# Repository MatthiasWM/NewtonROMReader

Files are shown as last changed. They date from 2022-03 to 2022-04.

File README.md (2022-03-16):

# NewtonROMReader

This archive contains the PCB layout and firmware source code for my Apple 
Newton MessagePad ROM board reader/programmer.

The Newton ROM Reader reads the contents of Apple MessagePad MP2x00 ROM
boards. Besides the well known US and German ROM, this programmer can read 
prototype ROM boards for further research.

Using the alternative Flash ROM Board, the ROM Reader can also program the
Flash chips and create new ROM Boards with patched or alternative 
operating systems. 

## CAUTION

 - Use an original Arduino Due. Do *NOT* use a Mega 2560!
 - Never insert or remove the ROM card while the programmer is powered!
 - All operations are final! There is no undo! There is no confirmation.

## Reader/Programmer

Assembling the Programmer requires some advanced soldering skills. The pin 
headers must be soldered around the outside of the board facing down. They 
must be flush with the PCB on the top, or the ROM board will not fit.

The SD Card connector is soldered to the underside of the board. The top
of the connector should be insulated using an ample amount of tape, avoiding
a short circuit with header pins on the Arduino. ALternatively, the colliding
pins on the Arduino board can be cut off.

The DIMM memory socket is more difficult to solder. The pin pitch is relatively
small. To make sure that the soldering is correct, the first tool to run
in the Programmer should be the short circuit test.

The last solder part is easy, but must not be forgotten. It's a jumper that 
sets the power to 3.2V. Connect the two eyes marked with an asterisk (*).

```
:
:   Lower left corner of the PCB
|
| ooo ooo
| ooo **o
|     ...... ........
+--------------------- - -
``` 

The Programmer board should be mounted on an Arduino Due. It *MUST NOT* be 
used with an Arduino Mega 1280/2560. The Mega runs at 5V and will likely
destroy any ROM, Flash, or SD card inserted into the Programmer. The Due runs
at the required 3.2V. If the large USB-A port of the Arduino blocks access to 
the SD Card slot, you have the wrong board!

The Programmer communicates with the user via USB connection to the Programming
port. No extra power connection is required. There is no extra software for
the Programmer. Users must use a serial terminal program to connect via the 
Programming USB port (57600 bps/baud 8N1).

## Firmware Source Code

The source code comes as an Arduino sketch `.ino` file and a number of 
additional source and header files. The "SdFat" library by Bill Greimann must be 
installed within the Arduino system `Tools > Manage Libraries...`.

Load the `.ino` file and set the board to `Arduino Due (Programming Port)`, 
then choose the right port from the `Tools > Port` menu.

Open the serial monitor `Tools > Serial Monitor` and press `Ctrl-U` to upload
the firmware to the Programmer.  

## PCB Layout

The Programmer PCB was designed with Eagle CAD 7.7.0 Stadard Edition. It's a
two layer board with no exeptional requirements.

The SO-DIMM 72 modules are not very common anymore and are somewhat hard to 
find. The SD Card socket is a standard SMD part. Pin headers should be 
square shaped to fit the Arduino receptacle well.

## Usage

The Programmer writes a 90's style menu over the USB serial port connection.
Functions can be selected by typing the command key and Return. 

 - `h`: Check all connectors on the board for short circuits. This tool helps
        verifying that there are no bridges in the SO DIMM connector soldering.
        *Never run this command with a ROM board or SD Card inserted!*
 - `0`: Select the ROM area from 0x00000000 to 0x00800000 which corresponds
        to the regular ROM and Apple system ROM extension (REx).
 - `1`: This page can be programmed with an extension block of up to 8MB.
 - `2`, `3`: Experimental blocks. These should be mapped to 0x10000000 and 
        can contain 8MB extensions each. This however is not yet verified.
 - `p`: Print the contents of the Flash as a hex dump with ASCII. Pressing 
        `return` will print the next block. Pressing any other key followed
        by `enter` will bring you back to the main menu. 
 - `c`: Check if the Flash memory is empty (all addresses return 0xFFFFFFFF).
 - `e`: Erase all sectors in the selected Flash area.
 - `w`: Write the content of a file on SD card or on an USB Drive to the 
        current Flash page. Filenames for pages 0 to 3 are set to "rom.bin",
        "rex1.bin", "rex2.bin", and "rex3.bin".
 - 'v': Verify the Flash content with the corresponding file on SD Card or 
        USB Drive.
  
## ToDo's

 - the SO DIMM footprint is really hard to solder, the pads are too big and 
   solder tends to short the pins
 - the LED can not be controlled because it is connected to a ROM Board output
 - address and data pins should be connected to 32 bit registers, making the 
   pin-by-pin addressing obsolete and the programmer much faster
 - the SPI port should be connected to a hardware SPI
 - there should be an option for a display and four buttons
 - the SD Card connecter must have pull-ups on most pins, and the Card 
   Detect and Write Protect pins should be connected to some pin

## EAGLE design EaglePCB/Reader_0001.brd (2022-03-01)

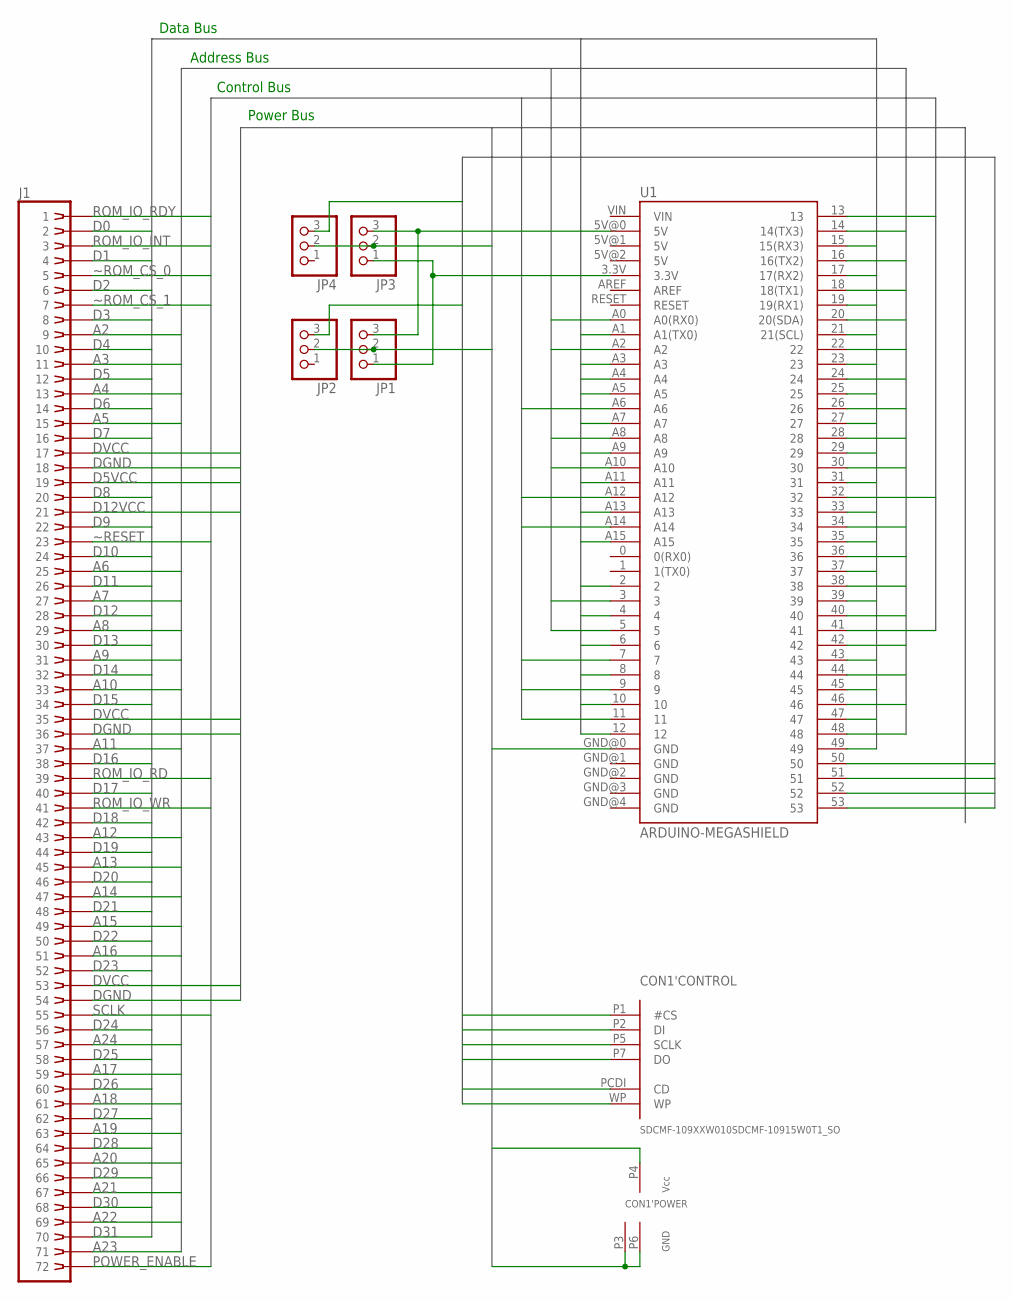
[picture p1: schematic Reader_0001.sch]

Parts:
CON1: SDCMF-109XXW010SDCMF-10915W0T1_SO; SDCMF-10915W0T1
J1: DIMM-M3; 177827-1
JP1, JP2, JP3, JP4: PINHD-1X3; 1X03
U1: ARDUINO-MEGASHIELD; ARDUINO_MEGA_SHIELD

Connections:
A2: J1.9, U1.5
A3: J1.11, U1.3
A4: J1.13, U1.A0 (A0(RX0))
A5: J1.15, U1.A2
A6: J1.25, U1.14 (14(TX3))
A7: J1.27, U1.16 (16(TX2))
A8: J1.29, U1.18 (18(TX1))
A9: J1.31, U1.20 (20(SDA))
A10: J1.33, U1.A8
A11: J1.37, U1.A10
A12: J1.43, U1.22
A13: J1.45, U1.24
A14: J1.47, U1.26
A15: J1.49, U1.28
A16: J1.51, U1.30
A17: J1.59, U1.36
A18: J1.61, U1.38
A19: J1.63, U1.40
A20: J1.65, U1.48
A21: J1.67, U1.46
A22: J1.69, U1.44
A23: J1.71, U1.42
A24: J1.57, U1.34
D0: J1.2, U1.12
D1: J1.4, U1.10
D2: J1.6, U1.8
D3: J1.8, U1.6
D4: J1.10, U1.4
D5: J1.12, U1.2
D5VCC: J1.19, JP1.2, JP2.2
D6: J1.14, U1.A1 (A1(TX0))
D7: J1.16, U1.A3
D8: J1.20, U1.A4
D9: J1.22, U1.A5
D10: J1.24, U1.A7
D11: J1.26, U1.15 (15(RX3))
D12: J1.28, U1.17 (17(RX2))
D12VCC: J1.21
D13: J1.30, U1.19 (19(RX1))
D14: J1.32, U1.21 (21(SCL))
D15: J1.34, U1.A9
D16: J1.38, U1.A11
D17: J1.40, U1.A13
D18: J1.42, U1.A15
D19: J1.44, U1.23
D20: J1.46, U1.25
D21: J1.48, U1.27
D22: J1.50, U1.29
D23: J1.52, U1.31
D24: J1.56, U1.33
D25: J1.58, U1.35
D26: J1.60, U1.37
D27: J1.62, U1.39
D28: J1.64, U1.49
D29: J1.66, U1.47
D30: J1.68, U1.45
D31: J1.70, U1.43
DGND: CON1.P3 (GND), CON1.P6 (GND), J1.18, J1.36, J1.54, U1.GND@0 (GND)
DVCC: CON1.P4 (VCC), J1.17, J1.35, J1.53, JP3.2, JP4.2
unnamed: JP1.3, JP3.3, U1.5V@0 (5V)
unnamed: JP1.1, JP3.1, U1.3.3V
POWER_ENABLE: J1.72, U1.41
ROM_IO_INT: J1.3, U1.11
ROM_IO_RD: J1.39, U1.A12
ROM_IO_RDY: J1.1, U1.13
ROM_IO_WR: J1.41, U1.A14
SCLK: J1.55, U1.32
SD_CD: CON1.PCDI (CD)
SD_CLCK: CON1.P5 (SCLK), U1.52
SD_CS: CON1.P1 (#CS), U1.53
SD_DI: CON1.P2 (DI), JP2.3, U1.51
SD_DO: CON1.P7 (DO), JP4.3, U1.50
SD_WP: CON1.WP
~RESET: J1.23, U1.A6
~ROM_CS_0: J1.5, U1.9
~ROM_CS_1: J1.7, U1.7

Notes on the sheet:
Data Bus
Address Bus
Control Bus
Power Bus

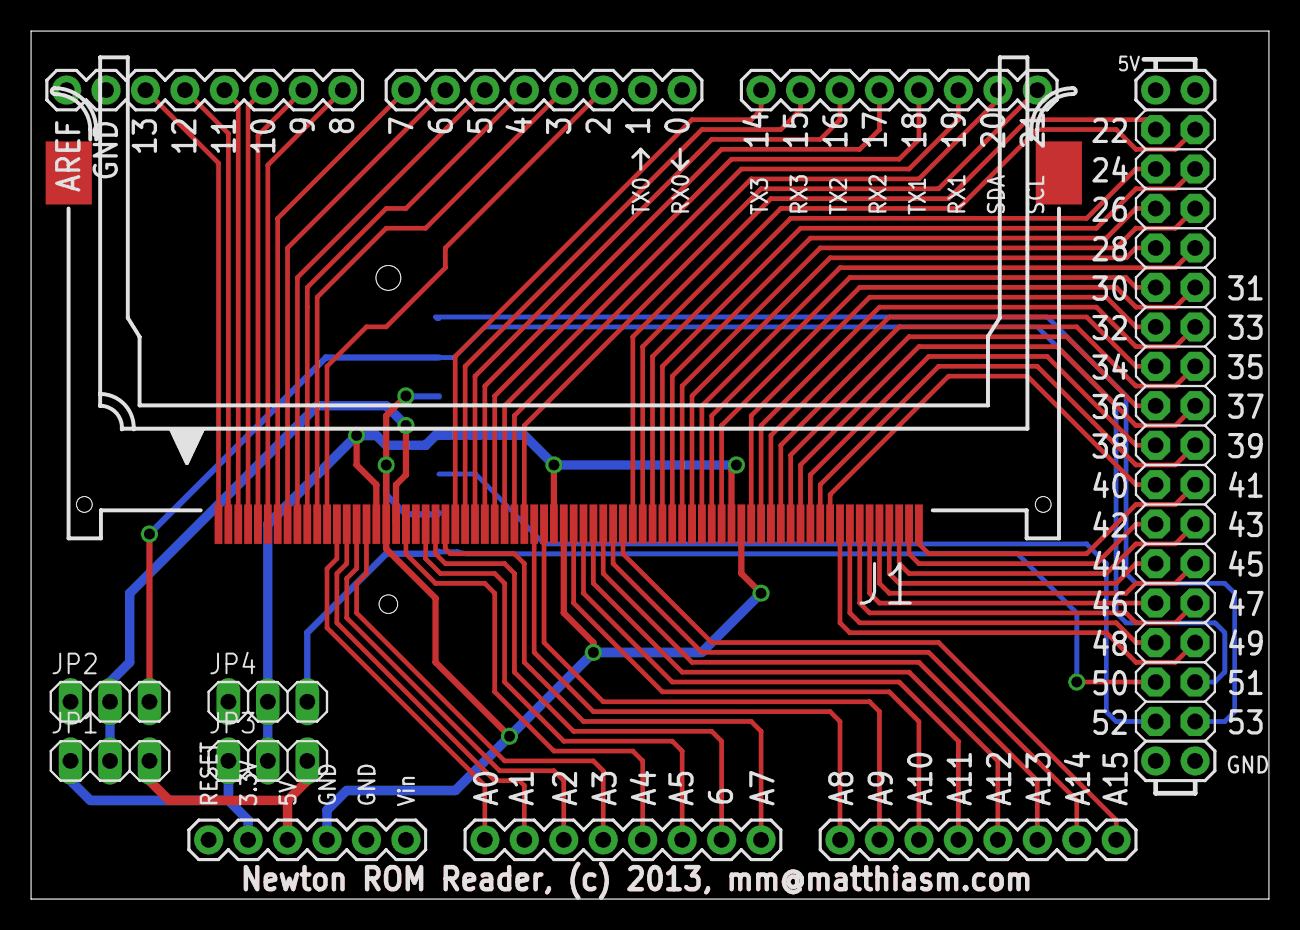
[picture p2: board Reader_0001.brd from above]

Board: 2 copper layers, 79.7 x 55.9 mm, 7 parts (1 on the bottom side), 73 nets.

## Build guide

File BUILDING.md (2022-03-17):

# Building the Hardware and Installing Software Components

 - Building the Newton ROM Reader PCB
 - Building the Newton ROM Reader firmware
 - Building the DCL Tools and Rex to generate ROM Extensions
 - (not yet) Installing the ARM Cross Assembler to Patch ROMs

## Building the Newton ROM Reader PCB

V1 of the ROM Reader PCB has a few issues, some of them are easy to fix, some are a bit more difficult.

Assembling the Programmer requires some advanced soldering skills. The pin 
headers must be soldered around the outside of the board facing down. They 
must be flush with the PCB on the top, or the ROM board will not fit.

The SD Card connector is soldered to the underside of the board. The top
of the connector should be insulated using an ample amount of tape, avoiding
a short circuit with header pins on the Arduino. Alternatively, the colliding
pins on the Arduino board can simply be cut off.

The DIMM memory socket is more difficult to solder. The pin pitch is relatively
small and the pads of the V1 board are too big. To make sure that the soldering 
is correct, the first tool to run in the Programmer should be the short circuit test.

There are three bridges that must be soldered. To amke sure that the board runs at
3.2V, a jumper that must be soldered, connecting the pins marked `1`. Two 10k 
resistors must be soldered, one connecting the pins marked `2`, and one connecting 
the pins marked `3`. Without resistors, the SD Card interface will not work
(Thanks to PCBman for finding this). 

The programmer will still recognize FAT32 fomatted USB Sticks, connect to the native
USB port via OTG cable.

```
:
:   Lower left corner of the PCB
|
| oo3 o22
| 3oo 11o
|     ...... ........
+--------------------- - -
``` 

The Programmer board should be mounted on an Arduino Due. It *MUST NOT* be 
used with an Arduino Mega 1280/2560. The Mega runs at 5V and will likely
destroy any ROM, Flash, or SD card inserted into the Programmer. The Due runs
at the required 3.2V. If the large USB-A port of the Arduino blocks access to 
the SD Card slot, you have the wrong board!

The Programmer communicates with the user via USB connection to the Programming
port. No extra power connection is required. There is no extra software for
the Programmer. Users must use a serial terminal program to connect via the 
Programming USB port (57600 bps/baud 8N1).

## Building the Newton ROM Reader firmware

To compile this firmware for the Newton ROM Programmer:

Downlaod and install the Arduino IDE (the developer environment) from [arduino.cc](https://www.arduino.cc/en/software).

Install the SdFat library by Bill Greiman, using the Arduino IDE menu `Tools > Manage Libraries...`.

Select the correct board via `Tools > Board > Arduino ARM 32 > Arduino Due (Programming Port)`. 
Connect to the Due `Programming Port` via USB and select the serial port `Tools > Port`.

Downlaod this project as a zip file or with `git clone`.
The archive *must* be located in a directory named `NewtonRomReader`. 
The Arduino IDE insists. Make sure you write `Rom`, not `ROM` in the filename
(Thanks to Pawel for finding this).

Open the `NewtonRomReader.ino` file in the Arduino developer environment.
It will open a single window with 12 or more  tabs for all the other source code files.

Press `Ctrl-R` (`Cmd-R` on Mac) and the program should compile (there may be warnings, but no errors).
Connect your Due and press `Ctrl-U` (`Cmd-U` on Mac) to upload your firmware into your Programmer.

Open the Serial Monitor that is part of the Arduino IDE (`Shift-Ctrl-M`, `Shift-Cmd-M`) and set the speed to 57600 baud.
You should see the ROM Programmer's menu on the serial port screen.

```
==============================
  Newton ROM Programmer V0.4
==============================

  h:  hardware test
  ...
```

Please run the hardware test before inserting any cards or testing anything else. If short circuits are found, brushing a dry 
toothbrush along the backside of the SO DIMM connector (the lengthy connector for the ROM Board) may fix the shorts.

## Building the DCL Tools and Rex to generate ROM Extensions

If you are planning to add Newton apps onto the ROM board, you need to get familiar with the _Rex_ tool. 
Rex is a command line tool that is part of the DCL toolbox. Compile and install Rex from the command line.

You will need to install [CMake](https://cmake.org/download/) and a C++ build environemnt (_Xcode_ on macOS, _VisualStudio_ on MSWindows,
_gcc_ on Linux).

```
# Download the source coee form GitHub:
git clone https://github.com/pguyot/DCL.git DCL.git
# Enter the source coee directory
cd DCL.git/
# Configure the build environment 
cmake -S . -B build -DCMAKE_BUILD_TYPE=Debug
# Build the library and the apps in DCL
cmake --build build/
# Installe Rex and other tools on your machine
cmake --install build/
```

Building a ROM Extension is explained [here](https://github.com/MatthiasWM/NewtonROMReader/wiki/Build-a-ROM-Extension).

## (todo) Installing the ARM Cross Assembler to Patch ROMs

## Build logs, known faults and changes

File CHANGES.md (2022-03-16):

## Versions

### Version 0.3 

Version 0.3 was mostly rewritten, adding support for USB Drives that can be 
connected to the native USB port via OTG cable. If no SD Card is found, we
check for a connected USB Drive. USB and SD drives can be hot swapped.

Menus were restructured, and menu commands were changed (sorry about that).
There is no longer a confirmation required for any operation, making it 
very easy to erase or overwrite a ROM with one keypress.

Pins are now set to inputs with a pullup after every operation, making an
accidental removal of a ROM card without powering down less harmful 
for the card.

### Version 0.2 

Version 0.2 is obsolete.

### Version 0.1 

The initial version is 0.1 which can erase, write, and verify the first ROM 
block and supports SD Cards.

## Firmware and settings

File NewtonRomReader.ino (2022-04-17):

// Please see BUILDING.md to build and install this file and other tools
//
// Written and tested for the Newton FLash ROM board with S29GL512 NOR Flash chips.
//

#include "NewtonRomReader.h"
#include "ROMCard.h"
#include "SDCard.h"
#include "menu.h"
#include "otg.h"

/**
 * Wait for a complete string, terminated by \n, while keeping the OTG system alive.
 * 
 * \return the string that was typed by the user, without the trailing \n.
 */
String serialReadString()
{
  String cmd;
//  int prevState = 0;
  for (;;) {
    if (uhgogo) {
      uhServer();
    }
//    if (uhstate.state!=prevState) {
//      printf("State changed from %d to %d\n", prevState, uhstate.state);
//      prevState = uhstate.state;
//    }
    if (Serial.available()>0) {
      char s = Serial.read();
      if (s=='\n')
        return cmd;
      if (s!='\r')
        cmd.concat(s);
    }
  }
}

/**
 * Print the name of a pin.
 * 
 * \param[in] i is *not* the pin number, but instead the position in the eggPin array.
 */
void printPin(int i)
{
  if (i > 44) {
    printf("A%d", i-43);
    return;
  }
  if (i > 12) {
    printf("D%d", i-13);
    return;
  }
  switch (i) {
    case 0: printf("SD_DO"); break;
    case 1: printf("SD_DI"); break;
    case 2: printf("SD_CLK"); break;
    case 3: printf("SD_CS"); break;
    case 4: printf("RESET"); break;
    case 5: printf("ROM_CS_0"); break;
    case 6: printf("ROM_CS_1"); break;
    case 7: printf("ROM_IO_RD"); break;
    case 8: printf("ROM_IO_WR"); break;
    case 9: printf("ROM_IO_INT"); break;
    case 10: printf("ROM_IO_RDY"); break;
    case 11: printf("POWER_ENABLE"); break;
    case 12: printf("SCLK"); break;
  }
}

// ---- CheckShortCicuits ------------------------------------

/**
 * Check if there are any short circuits between any of the
 * programmer pins and Vss.
 */
int testForShortCircuits()
{
  int nShorts = 0;
  
  printf("Check Programmer For Short Circuits...\n\n");
  
  // set all pins to input with pullup
  deactivateROMBus();
  deactivateSDBus();
  
  // check all pins for shortcuts agains ground
  printf("Testing for shorts to GND.\n");
  for (size_t i = 0; i < sizeof(eggPin); i++) {
    if (digitalRead(eggPin[i]) == 0) {
      printf("[ERROR] : Pin ");
      printPin(i);
      printf(" shorts with GND\n");
      nShorts++;
    }
  }
  
  // now check every pin against every other pin
  printf("Testing for shorts between pins.\n");
  for (size_t i = 0; i < sizeof(eggPin); i++) {
    digitalWrite(eggPin[i], 0);
    pinMode(eggPin[i], OUTPUT);
    for (size_t j = i + 1; j < sizeof(eggPin); j++) {
      if (digitalRead(eggPin[j]) == 0) {
        printf("[ERROR] : ");
        printPin(i);
        printf(" shorts with ");
        printPin(j);
        printf("\n");
        nShorts++;
      }
    }
    digitalWrite(eggPin[i], 1);
    pinMode(eggPin[i], INPUT_PULLUP);
  }

  // Give the user the result
  if (nShorts) {
    printf("\n[ERROR] : %d short circuits found.\n", nShorts);
    printf("[ERROR] : Please fix the board before using it.\n");
  } else {
    printf("\n[OK] : no short circuits found.\n");
  }

  return nShorts;
}

/**
 * User menu call to test board condition.
 */
void userCheckShortCicuits() {
  testForShortCircuits();
}

// ----------------------------------------------------------
// Verify the functions below.


// missing connection in Data lines: 00200000 => D21 = pin 48
// can't test all address lines without dumping the entire ROM

const  char *ascLut =
  "ABCDEFGHIJKLMNOP"
  "QRSTUVWXYZabcdef"
  "ghijklmnopqrstuv"
  "wxyz0123456789+/";


// 012345 670123 456701 234567 012345 67CCCC
void printEnc(unsigned long v)
{
  char d[7]; //, check = 0;
  d[0] = ascLut[v & 0x3f];
  v = v >> 6;
  d[1] = ascLut[v & 0x3f];
  v = v >> 6;
  d[2] = ascLut[v & 0x3f];
  v = v >> 6;
  d[3] = ascLut[v & 0x3f];
  v = v >> 6;
  d[4] = ascLut[v & 0x3f];
  v = v >> 6;
  d[5] = ascLut[v & 0x3f];
  d[6] = 0;
  printf("%s", d);
}

void writeFlash(uint32_t addr, uint32_t data)
{
  if (addr & 0x00000003) {
    printf("[INTERNAL_ERROR] : writeFlash: address must be word aligned: 0x%08lx\n", addr);
    return;
  }
  writeWord(0x0555 << 2, 0x00AA00AA);
  writeWord(0x02AA << 2, 0x00550055);
  writeWord(0x0555 << 2, 0x00A000A0);
  writeWord(addr, data);
  // FIXME: read status register
  delay(10);
  uint32_t w = readWord(addr);
  if (w != data) {
    printf("[ERROR] : readback failed at 0x%08lx: 0x%08lx!=0x%08lx\n",
           addr, data, w);
  }
}

// ---- Print Memory -----------------------------------------

/**
 * Read 512 bytes from memory and print a hex dump.
 * 
 * \param[in] addr start printing from this address
 * \return true
 */
bool printMemoryBlock(uint32_t addr) 
{
  activateControlBus();
  activateAddressBus();
  activateDataBusRead();

  for (uint32_t i=0; i<512; i+=16) {
    printf("%08lx: ", addr+i);
    uint32_t data[4];
    for (uint32_t j=0; j<4; j++) {
      data[j] = readWord(addr + i + j*4);
    }
    for (uint32_t j=0; j<4; j++) {
      printf("%08lx", data[j]);
    }
    printf(" |");
    for (uint32_t j=0; j<4; j++) {
      uint8_t c = data[j]>>24;
      printf("%c", (c<32||c>126) ? '.' : c);
      c = data[j]>>16;
      printf("%c", (c<32||c>126) ? '.' : c);
      c = data[j]>>8;
      printf("%c", (c<32||c>126) ? '.' : c);
      c = data[j];
      printf("%c", (c<32||c>126) ? '.' : c);
    }
    printf("|\n");
  }

  deactivateDataBus();
  deactivateAddressBus();
  deactivateControlBus();

  return true;
}

/**
 * Interactively print memeory blocks for current page.
 */
void userPrintMemory()
{
  uint32_t addr = gPageList[gCurrentPage].pStart;
  for (;;) {
    printMemoryBlock(addr);
    printf("Press [return] to continue, 'a'+[return] to abort.\n");
    String s = serialReadString();
    if (s.length()!=0) return;
    addr += 512;
  }
}

// ---- Test Empty -------------------------------------------

/**
 * Check if a block of memory is empty, i.e. all 0xffffffff.
 * 
 * \param[in] inStart check starting at this address
 * \param[in] inEnd check up to this address
 * 
 * \return true if the block is empty
 */
bool checkEmpty(uint32_t inStart, uint32_t inEnd)
{
  bool aborted = false;
  bool empty = true;
  printf("Press Return to abort:\n");
  printf(".___.___.___.___.___.___.___.___.\n|");
  fflush(stdout);
  
  activateControlBus();
  activateAddressBus();
  activateDataBusRead();
  
  for (uint32_t addr = inStart; addr < inEnd; addr += 4) {
    uint32_t v = readWord(addr);
    if (v != 0xFFFFFFFF) {
      printf("\nValue mismatch at address 0x%08lx: 0x%08lx\n", addr, v);
      empty = false;
      break;
    }
    if (Serial.read() == '\n') {
      aborted = true;
      break;
    }
    if ((addr & 0x0003ffff) == 0) {
      printf(":"); 
      fflush(stdout);
    }
  }
  
  deactivateDataBus();
  deactivateAddressBus();
  deactivateControlBus();

  printf("\n");
  if (aborted)
    printf("[Aborted] : Test aborted by user.\n");
  else if (empty)
    printf("[OK] : Flash memory is empty and ready to be programmed.\n");
  else
    printf("[Warning] : Flash memory is not empty.\n");
    
  return empty;
}

// ---- Erase Flash Memory -----------------------------------

/**
 * Erase a block of memory (set it to all 0xffffffff).
 * 
 * \param[in] inStart erase process starting at this address
 * \param[in] inEnd erase up to this address
 * 
 * \return true if the erase op did not trigger an error
 */
bool eraseFlash(uint32_t inStart, uint32_t inEnd)
{
  // Status:     bit7==0 if busy
  // if bit7==1: bit5==0 if erase successful
  //             bit4==0 if programming was successful

  const int kEraseTimeout = 200;
  int err = 0;
  printf("Press Return to abort:\n");
  printf(".___.___.___.___.___.___.___.___.\n|");
  fflush(stdout);

  activateControlBus();
  activateAddressBus();
  activateDataBusRead();

  uint32_t addr;
  for (addr = inStart; addr < inEnd; addr += 0x00040000) {
    uint32_t w;
    // clear status register
    writeWord(0x0555 << 2, 0x00710071);
    // Erase a sector (sector size id 0x00040000):
    writeWord(0x0555 << 2, 0x00AA00AA);
    writeWord(0x02AA << 2, 0x00550055);
    writeWord(0x0555 << 2, 0x00800080);
    writeWord(0x0555 << 2, 0x00AA00AA);
    writeWord(0x02AA << 2, 0x00550055);
    writeWord(addr, 0x00300030);
    int i;
    for (i = 0; i < kEraseTimeout; i++) {
      // read status register
      writeWord(0x0555 << 2, 0x00700070);
      w = readWord(0);
      if ((w & 0x00800080) == 0x00800080)
        break;
      delay(10); // Typical erase time: 62 * 10us = .6 seconds
    }
    if (i == kEraseTimeout) { // operation timed out
      err = 1; // timeout
      break;
    }
    if ((w & 0x00200020) != 0x00000000) {
      err = 3; // erase operation failed
      break;
    }
    if (Serial.read() == '\n') {
      err = 2; // aborted
      break;
    }
    printf(":");
    fflush(stdout);
  }

  deactivateDataBus();
  deactivateAddressBus();
  deactivateControlBus();

  printf("\n");
  if (err==0) 
    printf("[OK] : Flash memory is erased and ready to be programmed.\n");
  else if (err==1)
    printf("[ERROR] : Timeout error at address 0x%08lx.\n", addr);
  else if (err==2)
    printf("[Aborted] : Operation aborted by user.\n");
  else if (err==3)
    printf("[ERROR] : Erase operation failed at address 0x%08lx.\n", addr);
    
  return (err==0);
}

// ---- Program ROM File -------------------------------------

/**
 * Program the contents of a file on SD Card or an OTG Drive to a block of Flash memory .
 * 
 * \param[in] inStart programming process starting at this address
 * \param[in] inEnd program up to this address or until the end of file
 * \param[in] inFilename write contents to this file
 * 
 * \return true if the write op did not trigger an error or warning
 */
bool programFlash(uint32_t inStart, uint32_t inEnd, String inFilename)
{
  const int kWriteTimeout = 100;
  int err = 0;
  bool useSD = true;
  FIL fd;

  if (initSDCard()==false) {
    if (uhstate.state!=UHSTAT_READY) {
      printf("[ERROR] : No SD card found, no USB drive found.\n");
      return false;
    }
    useSD = false;
  }

  if (useSD) {
    if (!file.open(inFilename.c_str(), O_RDONLY)) {
      printf("[ERROR] : Can't open file \"%s\" on SD card.\n", inFilename.c_str());
      return false;
    }
  } else {
    if (f_open(&fd, inFilename.c_str(), FA_READ) != 0) {
      printf("[ERROR] : Can't open file \"%s\" on USB drive.\n", inFilename.c_str());
      return false;
    }
  }
  
  printf("Press Return to abort:\n");
  printf(".___.___.___.___.___.___.___.___.\n|");
  fflush(stdout);
  
  activateControlBus();
  activateAddressBus();
  activateDataBusRead();

  const uint32_t nWords = 256;
  uint32_t addr;
  for (addr = inStart; addr < inEnd; addr += (4*nWords)) {
    // write sequence to prepare Flash for programming
    writeWord(0x0555 << 2, 0x00AA00AA);
    writeWord(0x02AA << 2, 0x00550055);
    writeWord(addr, 0x00250025); // addr should be SA
    writeWord(addr, ((nWords-1)<<16)|(nWords-1)); // addr should be SA, arg is number of words to write minus one
    // write buffer
    for (uint32_t j=0; j<nWords; j++) {
      uint32_t vFile = 0xffffffff;
      if (useSD) {
        int n = file.read(&vFile, 4);
        vFile = htonl(vFile);
        if (n==0) err = 4;
      } else {
        UINT n = 0;
        f_read (&fd, &vFile, 4, &n);
        vFile = htonl(vFile);
        if (n==0) err = 4;
      }
      writeWord(addr+(j<<2), vFile);
    }
    // confirm write
    writeWord(addr, 0x00290029); // addr should be SA
    // wait for operation to complete
    int t;
    uint32_t w;
    for (t = 0; t < kWriteTimeout; t++) {
      // read status register
      writeWord(0x0555 << 2, 0x00700070);
      w = readWord(0);
      if ((w & 0x00800080) == 0x00800080)
        break;
      delay(1); // There should be little to no delay needed.
    }
    if (t == kWriteTimeout) {
      err = 2; // timeout
      break;
    }
    if ((w & 0x00100010) != 0x00000000) {
      err = 3; // write operation failed
      break;
    }
    if (Serial.read() == '\n') {
      err = 1; // aborted
      break;
    }
    if (err==4)
      break;
    if ((addr & 0x0003ffff) == 0) {
      printf(":");
      fflush(stdout);
    }
  }

  deactivateDataBus();
  deactivateAddressBus();
  deactivateControlBus();

  if (useSD) {
    file.close();
    sd.end();
  } else {
    f_close(&fd);
  }

  printf("\n");
  if (err==0)
    printf("[OK] : Successfully programmed Flash memory with file contents.\n");
  else if (err==1)
    printf("[Aborted] : Operation aborted by user. Flash memory partially written.\n");
  else if (err==2)
    printf("[ERROR] : Write operation timed out at address 0x%08lx.\n", addr);
  else if (err==3)
    printf("[ERROR] : Write operation failed at address 0x%08lx.\n", addr);
  else if (err==4)
    printf("[Warning] : Successfully programmed Flash to end of file at address 0x%08lx.\n"
           "            Remaining memory unchanged.\n", addr);
    
  return (err==0);
}

// ---- Verify Flash Memory Block -------------------------------------

/**
 * Verify a block of Flash memeory to a file on SD Card or an OTG Drive.
 * 
 * \param[in] inStart verification process starting at this address
 * \param[in] inEnd verify up to this address or until the end of file
 * \param[in] inFilename compare to this file
 * 
 * \return true if the verify op did not trigger an error
 */
bool verifyFlash(uint32_t inStart, uint32_t inEnd, String inFilename)
{
  int err = 0;
  bool useSD = true;
  FIL fd;

  if (initSDCard()==false) {
    if (uhstate.state!=UHSTAT_READY) {
      printf("[ERROR] : No SD card found, no USB drive found.\n");
      return false;
    }
    useSD = false;
  }

  if (useSD) {
    if (!file.open(inFilename.c_str(), O_RDONLY)) {
      printf("[ERROR] : Can't open file \"%s\" on SD card.\n", inFilename.c_str());
      return false;
    }
  } else {
    if (f_open(&fd, inFilename.c_str(), FA_READ) != 0) {
      printf("[ERROR] : Can't open file \"%s\" on USB drive.\n", inFilename.c_str());
      return false;
    }
  }
  
  printf("Press Return to abort:\n");
  printf(".___.___.___.___.___.___.___.___.\n|");
  fflush(stdout);
  
  activateControlBus();
  activateAddressBus();
  activateDataBusRead();
  
  uint32_t addr, vFile, vFlash;
  for (addr = inStart; addr < inEnd; addr += 4) {
    vFile = vFlash = 0xffffffff;
    if (useSD) {
      int n = file.read(&vFile, 4);
      vFile = htonl(vFile);
      if (n<=0) {
        err = 3;
        break;
      }
    } else {
      UINT n = 0;
      f_read (&fd, &vFile, 4, &n);
      vFile = htonl(vFile);
      if (n<=0) {
        err = 3;
        break;
      }
    }
    vFlash = readWord(addr);
    if (vFlash != vFile) {
      err = 2;
      break;
    }
    if (Serial.read() == '\n') {
      err = 1;
      break;
    }
    if ((addr & 0x0003ffff) == 0) {
      printf(":");
      fflush(stdout);
    }
  }
  
  deactivateDataBus();
  deactivateAddressBus();
  deactivateControlBus();

  if (useSD) {
    file.close();
    sd.end();
  } else {
    f_close(&fd);
  }

  printf("\n");
  if (err==0)
    printf("[OK] : Flash memory and file contents are the same.\n");
  else if (err==1)
    printf("[Aborted] : Operation aborted by user.\n");
  else if (err==2)
    printf("[ERROR] : Contents differs at address 0x%08lx (0x%08lx!=0x%08lx).\n", addr, vFlash, vFile);
  else if (err==3)
    printf("[Warning] : Contents is the same up to end of file at address 0x%08lx.\n"
           "            Remaining memory unchecked.\n", addr);
    
  return (err==0);
}

void verifyFlash(Page &inPage)
{
  verifyFlash(inPage.pStart, inPage.pEnd, inPage.pFilename);
}

// ---- Read Flash Memory Block and write it to Mass Storage -------------------------------------

/**
 * Read a block of Flash memeory and write it to a file on SD Card or an OTG Drive.
 * 
 * \param[in] inStart copying process starting at this address
 * \param[in] inEnd copy up to this address
 * \param[in] inFilename overwrite this file
 * 
 * \return true if the copy op did not trigger an error
 */
bool readFlash(uint32_t inStart, uint32_t inEnd, String inFilename)
{
  int err = 0;
  bool useSD = true;
  FIL fd;

  if (initSDCard()==false) {
    if (uhstate.state!=UHSTAT_READY) {
      printf("[ERROR] : No SD card found, no USB drive found.\n");
      return false;
    }
    useSD = false;
  }

  if (useSD) {
    if (!file.open(inFilename.c_str(), O_WRONLY)) {
      printf("[ERROR] : Can't open file \"%s\" on SD card.\n", inFilename.c_str());
      return false;
    }
  } else {
    // http://mercury.pr.erau.edu/~siewerts/cec450/code/FreeRTOSExampleCode/Demo/Common/FileSystem/FatFs-0.7e/doc/en/open.html
    if (f_open(&fd, inFilename.c_str(), FA_WRITE|FA_CREATE_ALWAYS) != 0) {
      printf("[ERROR] : Can't open file \"%s\" on USB drive.\n", inFilename.c_str());
      return false;
    }
  }
  
  printf("Press Return to abort:\n");
  printf(".___.___.___.___.___.___.___.___.\n|");
  fflush(stdout);
  
  activateControlBus();
  activateAddressBus();
  activateDataBusRead();
  
  uint32_t addr, vFlash;
  for (addr = inStart; addr < inEnd; addr += 4) {
    vFlash = readWord(addr);
    vFlash = htonl(vFlash);
    if (useSD) {
      int n = file.write(&vFlash, 4);
      if (n<=0) {
        err = 3;
        break;
      }
    } else {
      UINT n = 0;
      f_write(&fd, &vFlash, 4, &n);
      if (n<=0) {
        err = 3;
        break;
      }
    }
    if (Serial.read() == '\n') {
      err = 1;
      break;
    }
    if ((addr & 0x0003ffff) == 0) {
      printf(":");
      fflush(stdout);
    }
  }
  
  deactivateDataBus();
  deactivateAddressBus();
  deactivateControlBus();

  if (useSD) {
    file.close();
    sd.end();
  } else {
    f_close(&fd);
  }

  printf("\n");
  if (err==0)
    printf("[OK] : Flash memory copied to file.\n");
  else if (err==1)
    printf("[Aborted] : Operation aborted by user.\n");
  else if (err==3)
    printf("[Warning] : Copying Flash memory to file failed at address 0x%08lx.\n", addr);
    
  return (err==0);
}

void readFlash(Page &inPage)
{
  readFlash(inPage.pStart, inPage.pEnd, inPage.pFilename);
}

// ---- Test 1 -----------------------------------------------

// ROM Board connectors:
//        X[------ address bus --------]
// 3322.2222:2222.1111:1111.11
// 1098.7654:3210.9876:5432.1098:7654.3210
// CS0 --> A25
// CS0 & CS1 --> CE
//
//  CS0 CS1 | A25 CE
// ---------+--------
//   0   0  |  0   0  - not allowed
//   0   1  |  0   0  - access 0x0000.0000 to 0x01ff.ffff (32MB)
//   1   0  |  1   0  - access 0x0200.0000 to 0x03ff.ffff (32MB)
//   1   1  |  1   1  - ROM disabled
//
//  Programmer   MessagePad
//   Address      Address     ID    page #, filename
// ----------------------------------------------------------
// 0x0000.0000: 0x0000.0000: ROM   (page 0, rom.bin)
// 0x0080.0000: 0x0080.0000: REx1  (page 1, rex1.bin)
// 0x0100.0000: 0x0100.0000: fault, but could probably be mapped to REx2
// 0x0180.0000: 0x0180.0000: fault, but could probably be mapped to REx3
// 0x0200.0000: 0x1000.0000: REx4  (page 2, rex2.bin)
// 0x0280.0000: 0x1080.0000: REx5  (page 3, rex3.bin)
// 0x0300.0000: 0x1100.0000: REx6
// 0x0380.0000: 0x1180.0000: REx7
//              0x1200.0000: REx4 mirror prev ROMs up to 0x2000.0000

/**
 * This writes a unique value at every 8MB block. 
 * 
 * I used Hammer to find these blocks again on the MessagePad. Turns 
 * out that the first 16MB of ROM are mapped to address 0. The second 
 * 16MB block is not mapped, but I have a feeling that modifying the 
 * MMU LUT could map this block into the second 16MB of the system. 
 * They would not be discovered by the NewtonOS though.
 * 
 * The upper 32MB of our board are mapped to 0x1000.0000. The first 
 * 16MB can contain more ROM Extensions. I don't know if the remain 
 * 16MB can be used by the OS.
 */
void userTest1()
{
//eraseFlash(0x00000000, 0x00000000); // ROM + Apple REX 0
//eraseFlash(0x00800000, 0x00800000); // REX 1
  eraseFlash(0x01000000, 0x01000000); // REX 2
  eraseFlash(0x01800000, 0x01800000); // REX 3
  eraseFlash(0x02000000, 0x02000000); // ??
  eraseFlash(0x02800000, 0x02800000); // ??
  eraseFlash(0x03000000, 0x03000000); // ??
  eraseFlash(0x03800000, 0x03800000); // ??

  activateControlBus();
  activateAddressBus();
  activateDataBusRead();
  
  writeFlash(0x01000000, 0x52457832); // "REx2"
  writeFlash(0x01800000, 0x52457833);
  writeFlash(0x02000000, 0x52457834);
  writeFlash(0x02800000, 0x52457835);
  writeFlash(0x03000000, 0x52457836);
  writeFlash(0x03800000, 0x52457837);
  
  deactivateDataBus();
  deactivateAddressBus();
  deactivateControlBus();
}

// -----------------------------------------------------------

void userCheckEmpty(int inPage)
{
  if (inPage==-1) 
  inPage = gCurrentPage;
  Page &pg = gPageList[inPage];
  printf("Checking if \"%s\" is empty...\n", gPageList[gCurrentPage].pName);
  checkEmpty(pg.pStart, pg.pEnd);
}

void userErasePage(int inPage)
{
  if (inPage==-1) 
  inPage = gCurrentPage;
  Page &pg = gPageList[inPage];

  printf("Erasing \"%s\"...\n", gPageList[gCurrentPage].pName);
  eraseFlash(pg.pStart, pg.pEnd);
}
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
void loop()
{
  printf("\n\n");
  printf("==============================\n");
  printf("  Newton ROM Programmer V0.4\n");
  printf("==============================\n\n");
  
  for (auto &menuitem : gMenuItemList) {
    menuitem->print();
  }
  
  printf("Current page is \"%s\" (\"%s\").\n",
         gPageList[gCurrentPage].pName,
         gPageList[gCurrentPage].pFilename);
  
  printf("\n> ");
  fflush(stdout);
  String s = serialReadString();
  printf("%s\n\n", s.c_str());
  
  for (auto &menuitem : gMenuItemList) {
    if (s.equals(menuitem->cmd())) {
      menuitem->run();
      break;
    }
  }
}

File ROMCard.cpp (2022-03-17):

#include "ROMCard.h"

int gCurrentPage = 0;
uint32_t gCurrentAddress = 0;

static bool sAddressPinsUndefined = true;

std::vector <Page> gPageList = {
  { 0x00000000, 0x00800000, "ROM page", "rom.bin" },
  { 0x00800000, 0x01000000, "ROM Extension 1", "rex1.bin" },
  { 0x02000000, 0x02800000, "ROM Extension 2", "rex2.bin" },
  { 0x02800000, 0x03000000, "ROM Extension 3", "rex3.bin" },
  { 0x00000000, 0x01000000, "ROM & ext1", "romrex1.bin" },
  { 0x02000000, 0x03000000, "ext2 & ext3", "rex23.bin" },
//{ 0x00000000, 0x02000000, "full card", "card.bin" },
};


void dataBus(bool active)
{
  int mode = active ? OUTPUT : INPUT_PULLUP;
//  int mode = active ? OUTPUT : INPUT;
  pinMode(eggD0, mode);
  pinMode(eggD1, mode);
  pinMode(eggD2, mode);
  pinMode(eggD3, mode);
  pinMode(eggD4, mode);
  pinMode(eggD5, mode);
  pinMode(eggD6, mode);
  pinMode(eggD7, mode);
  pinMode(eggD8, mode);
  pinMode(eggD9, mode);
  pinMode(eggD10, mode);
  pinMode(eggD11, mode);
  pinMode(eggD12, mode);
  pinMode(eggD13, mode);
  pinMode(eggD14, mode);
  pinMode(eggD15, mode);
  pinMode(eggD16, mode);
  pinMode(eggD17, mode);
  pinMode(eggD18, mode);
  pinMode(eggD19, mode);
  pinMode(eggD20, mode);
  pinMode(eggD21, mode);
  pinMode(eggD22, mode);
  pinMode(eggD23, mode);
  pinMode(eggD24, mode);
  pinMode(eggD25, mode);
  pinMode(eggD26, mode);
  pinMode(eggD27, mode);
  pinMode(eggD28, mode);
  pinMode(eggD29, mode);
  pinMode(eggD30, mode);
  pinMode(eggD31, mode);
}

void activateDataBusWrite() { dataBus(true); }
void activateDataBusRead() { dataBus(false); }
void deactivateDataBus() { dataBus(false); }

void addressBus(bool active)
{
  int mode = active ? OUTPUT : INPUT_PULLUP;
  pinMode(eggA2, mode);    // 0x00000004
  pinMode(eggA3, mode);    // 0x00000008
  pinMode(eggA4, mode);    // 0x00000010
  pinMode(eggA5, mode);    // 0x00000020
  pinMode(eggA6, mode);    // 0x00000040
  pinMode(eggA7, mode);    // 0x00000080
  pinMode(eggA8, mode);    // 0x00000100
  pinMode(eggA9, mode);    // 0x00000200
  pinMode(eggA10, mode);   // 0x00000400
  pinMode(eggA11, mode);   // 0x00000800
  pinMode(eggA12, mode);   // 0x00001000
  pinMode(eggA13, mode);   // 0x00002000
  pinMode(eggA14, mode);   // 0x00004000
  pinMode(eggA15, mode);   // 0x00008000
  pinMode(eggA16, mode);   // 0x00010000
  pinMode(eggA17, mode);   // 0x00020000
  pinMode(eggA18, mode);   // 0x00040000
  pinMode(eggA19, mode);   // 0x00080000
  pinMode(eggA20, mode);   // 0x00100000
  pinMode(eggA21, mode);   // 0x00200000
  pinMode(eggA22, mode);   // 0x00400000
  pinMode(eggA23, mode);   // 0x00800000
  pinMode(eggA24, mode);   // 0x01000000
  sAddressPinsUndefined = true;
}

void activateAddressBus() { addressBus(true); }
void deactivateAddressBus() { addressBus(false); }

/**
 * Set an address on the address bus.
 * 
 * \param[in] inAddress valid addresses are 0-32MB ind 4 byte steps
 */
void setAddress(uint32_t inAddress)
{
#if 1 // slower version
  uint32_t a = inAddress;
  a >>= 1;
  a >>= 1;
  digitalWrite(eggA2, a & 1); a >>= 1;
  digitalWrite(eggA3, a & 1); a >>= 1;
  digitalWrite(eggA4, a & 1); a >>= 1;
  digitalWrite(eggA5, a & 1); a >>= 1;
  digitalWrite(eggA6, a & 1); a >>= 1;
  digitalWrite(eggA7, a & 1); a >>= 1;
  digitalWrite(eggA8, a & 1); a >>= 1;
  digitalWrite(eggA9, a & 1); a >>= 1;
  digitalWrite(eggA10, a & 1); a >>= 1;
  digitalWrite(eggA11, a & 1); a >>= 1;
  digitalWrite(eggA12, a & 1); a >>= 1;
  digitalWrite(eggA13, a & 1); a >>= 1;
  digitalWrite(eggA14, a & 1); a >>= 1;
  digitalWrite(eggA15, a & 1); a >>= 1;
  digitalWrite(eggA16, a & 1); a >>= 1;
  digitalWrite(eggA17, a & 1); a >>= 1;
  digitalWrite(eggA18, a & 1); a >>= 1;
  digitalWrite(eggA19, a & 1); a >>= 1;
  digitalWrite(eggA20, a & 1); a >>= 1;
  digitalWrite(eggA21, a & 1); a >>= 1;
  digitalWrite(eggA22, a & 1); a >>= 1;
  digitalWrite(eggA23, a & 1); a >>= 1;
  digitalWrite(eggA24, a & 1); a >>= 1;
#elif 0 // faster version
  if (sAddressPinsUndefined)
    gCurrentAddress = ~inAddress;
  uint32_t a = inAddress;
  uint32_t m = inAddress ^ gCurrentAddress;
  a >>= 1; m >>= 1;
  a >>= 1; m >>= 1;
  if (m&1) digitalWrite(eggA2, a & 1); a >>= 1; m >>= 1;
  if (m&1) digitalWrite(eggA3, a & 1); a >>= 1; m >>= 1;
  if (m&1) digitalWrite(eggA4, a & 1); a >>= 1; m >>= 1;
  if (m&1) digitalWrite(eggA5, a & 1); a >>= 1; m >>= 1;
  if (m&1) digitalWrite(eggA6, a & 1); a >>= 1; m >>= 1;
  if (m&1) digitalWrite(eggA7, a & 1); a >>= 1; m >>= 1;
  if (m&1) digitalWrite(eggA8, a & 1); a >>= 1; m >>= 1;
  if (m&1) digitalWrite(eggA9, a & 1); a >>= 1; m >>= 1;
  if (m&1) digitalWrite(eggA10, a & 1); a >>= 1; m >>= 1;
  if (m&1) digitalWrite(eggA11, a & 1); a >>= 1; m >>= 1;
  if (m&1) digitalWrite(eggA12, a & 1); a >>= 1; m >>= 1;
  if (m&1) digitalWrite(eggA13, a & 1); a >>= 1; m >>= 1;
  if (m&1) digitalWrite(eggA14, a & 1); a >>= 1; m >>= 1;
  if (m&1) digitalWrite(eggA15, a & 1); a >>= 1; m >>= 1;
  if (m&1) digitalWrite(eggA16, a & 1); a >>= 1; m >>= 1;
  if (m&1) digitalWrite(eggA17, a & 1); a >>= 1; m >>= 1;
  if (m&1) digitalWrite(eggA18, a & 1); a >>= 1; m >>= 1;
  if (m&1) digitalWrite(eggA19, a & 1); a >>= 1; m >>= 1;
  if (m&1) digitalWrite(eggA20, a & 1); a >>= 1; m >>= 1;
  if (m&1) digitalWrite(eggA21, a & 1); a >>= 1; m >>= 1;
  if (m&1) digitalWrite(eggA22, a & 1); a >>= 1; m >>= 1;
  if (m&1) digitalWrite(eggA23, a & 1); a >>= 1; m >>= 1;
  if (m&1) digitalWrite(eggA24, a & 1); a >>= 1; m >>= 1;
#else
  // make sure that all address pins are refreshed
  if (sAddressPinsUndefined)
    gCurrentAddress = ~inAddress;

  // update only the pins that changed
  uint32_t a = inAddress;
  uint32_t m = inAddress ^ gCurrentAddress;
  a >>= 1; m >>= 1;
  a >>= 1; m >>= 1;
  for (int i=kAddrMin; i<=kAddrMax; i++) {
    if (m&1) digitalWrite(gAdrressLut[i], a & 1); 
    a >>= 1; m >>= 1;
  }
#endif
  // set the global address, so we can optimize pin update
  // also, gCurrentAddress is used to determine the corresponding CS
  gCurrentAddress = inAddress;
}

void activateControlBus()
{
  digitalWrite(eggRESET, 1);
  pinMode(eggRESET, OUTPUT); // inv
  digitalWrite(eggROM_CS_0, 1);
  pinMode(eggROM_CS_0, OUTPUT); // inv
  digitalWrite(eggROM_CS_1, 1);
  pinMode(eggROM_CS_1, OUTPUT); // inv
  digitalWrite(eggROM_IO_RD, 1);
  pinMode(eggROM_IO_RD, OUTPUT);
  digitalWrite(eggROM_IO_WR, 1);
  pinMode(eggROM_IO_WR, OUTPUT);
  pinMode(eggROM_IO_INT, INPUT);
  pinMode(eggROM_IO_RDY, INPUT);
  digitalWrite(eggPOWER_ENABLE, 1);
  pinMode(eggPOWER_ENABLE, OUTPUT);
}

void deactivateControlBus()
{
  pinMode(eggRESET, INPUT_PULLUP);
  pinMode(eggROM_CS_0, INPUT_PULLUP);
  pinMode(eggROM_CS_1, INPUT_PULLUP);
  pinMode(eggROM_IO_RD, INPUT_PULLUP);
  pinMode(eggROM_IO_WR, INPUT_PULLUP);
  pinMode(eggROM_IO_INT, INPUT_PULLUP);
  pinMode(eggROM_IO_RDY, INPUT_PULLUP);
  pinMode(eggPOWER_ENABLE, INPUT_PULLUP);
}

void deactivateROMBus()
{
  deactivateDataBus();
  deactivateAddressBus();
  deactivateControlBus();
}

void setupROMBus()
{
  deactivateROMBus();
}
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

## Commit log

2022-03-01 Initial commmit
    [Reader_0001.brd, Reader_0001.sch]
2022-03-17 Fixed case in include file name
    [NewtonRomReader.ino, ROMCard.h]
2022-04-06 Adding sample code for programming the board in situ.

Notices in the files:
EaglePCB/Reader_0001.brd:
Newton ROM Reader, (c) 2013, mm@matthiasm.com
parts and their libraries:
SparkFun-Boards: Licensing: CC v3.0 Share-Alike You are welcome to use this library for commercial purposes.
